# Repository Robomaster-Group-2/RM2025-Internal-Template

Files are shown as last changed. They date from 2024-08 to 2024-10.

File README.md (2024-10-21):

# RM2025-Internal-Template

This is the template project for RM2025 Internal competition.

## Quick start guide

To use this template, clone the template in your terminal with:

```bash
git clone git@github.com:hkustenterprize/RM2025-Internal-Template.git
```

enter the directory with:

```bash
cd RM2025-Internal-Template
```

compile with Makefile

```bash
make -j
```

## Structure

- The directory `./Drivers` and `./Middlewares` contains the HAL drivers generated by CubeMX, you may ignore them.
- The directory `./RM2025-Internal-Core` contains the drivers. You may ignore the FreeRTOS and diagnostic directories as we have already set them up for you.
- You have to implement your own drivers, such as rc or motors driver in `./RM2025-Internal-Core\Drivers`
- You may use the drivers in the Core directory developed by you and implement applications of the tasks in `./Core\Src` and `./Core\Inc`
- Within `./Core/Inc/AppConfig.h`, you could enable/disable certain drivers and configure them. Port configurations had been configured according to the Internal board design.
- Tasks are created in `./Core/Src/UserTask.cpp`. You may set initializing code here
- Most of your code may happen in `./RM2025-Internal-Core/Drivers` and `./Core/Src`.

Wish good luck.

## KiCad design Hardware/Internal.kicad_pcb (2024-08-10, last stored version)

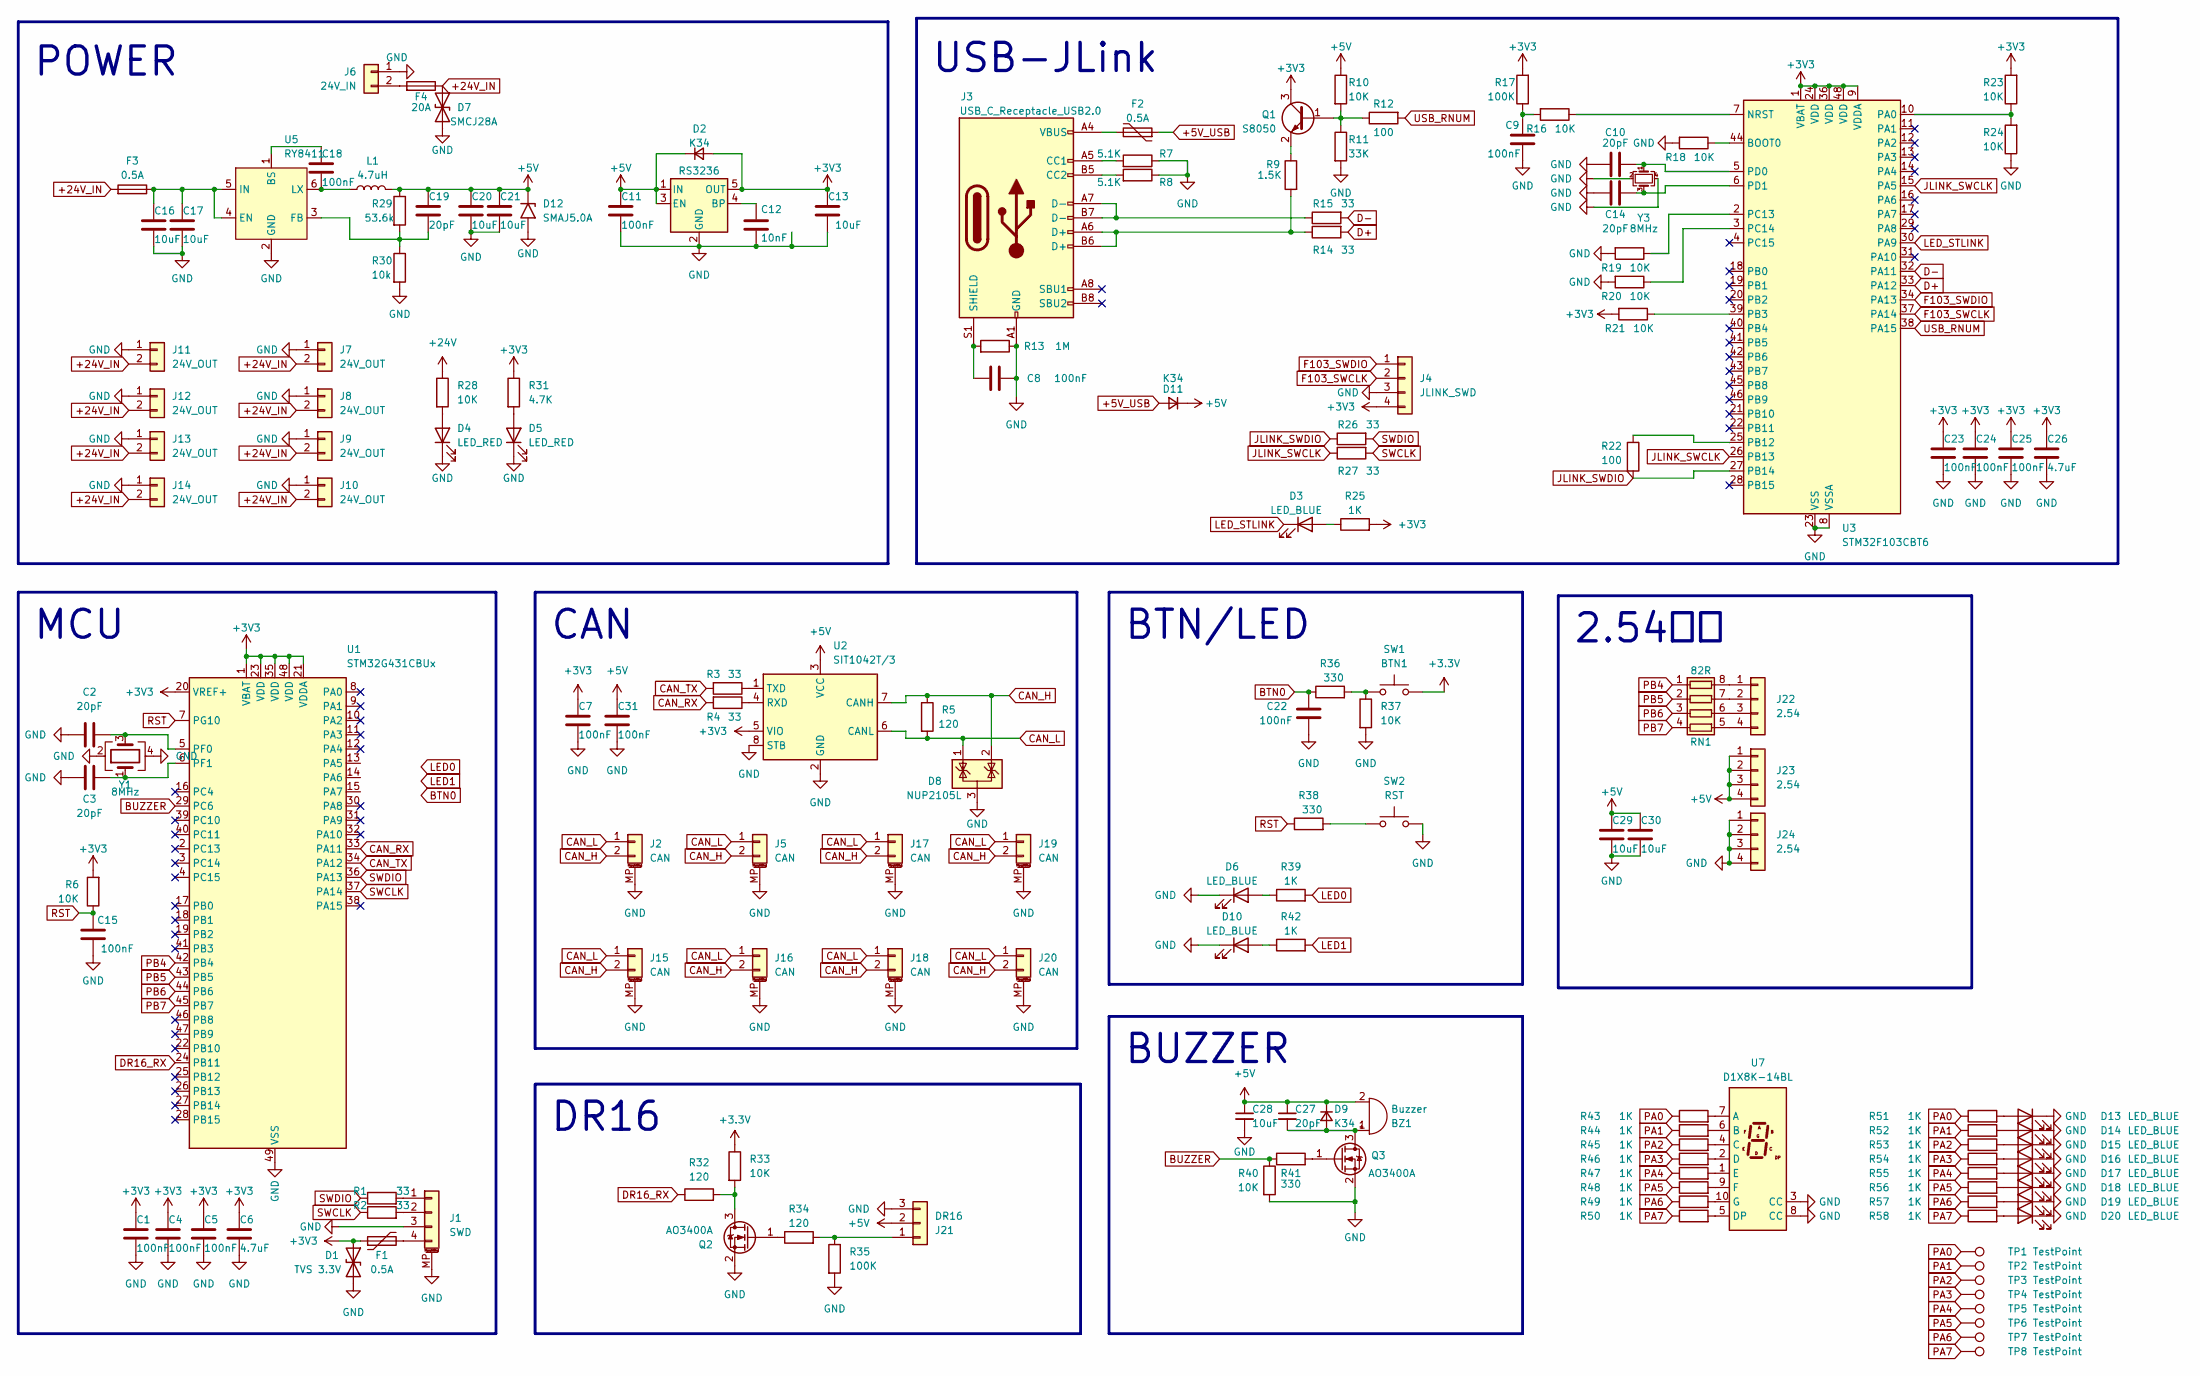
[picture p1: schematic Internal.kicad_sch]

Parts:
BZ1: Buzzer; MLT-9032
C1, C4, C5, C7, C8, C9, C11, C15, C18, C22, C23, C24, C25, C31: 100nF; C_0603_1608Metric
C2, C3, C10, C14, C19, C27: 20pF; C_0603_1608Metric
C6, C26: 4.7uF; C_0603_1608Metric
C12: 10nF; C_0603_1608Metric
C13, C28: 10uF; C_0603_1608Metric
C16, C17, C20, C21, C29, C30: 10uF; C_1206_3216Metric
D1: TVS 3.3V; D_SMF
D2, D9, D11: K34; D_SMF
D3, D6, D10, D13, D14, D15, D16, D17, D18, D19, D20: LED_BLUE; LED_0603_1608Metric
D4, D5: LED_RED; LED_0603_1608Metric
D7: SMCJ28A; D_SMC
D8: NUP2105L; SOT-23
D12: SMAJ5.0A; D_SMA
F1, F2, F3: 0.5A; Fuse_1206_3216Metric
F4: 20A; 1808_Fuse
J1: SWD; Molex_PicoBlade_53398-0471_1x04-1MP_P1.25mm_Vertical
J2, J5, J15, J16, J17, J18, J19, J20: CAN; JST_GH_BM02B-GHS-TBT_1x02-1MP_P1.25mm_Vertical
J3: USB_C_Receptacle_USB2.0; USB_C_Receptacle_HRO_TYPE-C-31-M-12_NO_HOLE
J4: JLINK_SWD; Molex_PicoBlade_53047-0410_1x04_P1.25mm_Vertical
J6: 24V_IN; AMASS_XT30U-M_1x02_P5.0mm_Vertical
J7, J8, J9, J10, J11, J12, J13, J14: 24V_OUT; AMASS_XT30U-F_1x02_P5.0mm_Vertical
J21: DR16; PinHeader_1x03_P2.54mm_Vertical
J22, J23, J24: 2.54; PinSocket_1x04_P2.54mm_Vertical
L1: 4.7uH; L_Cenker_CKCS4020
Q1: S8050; SOT-23
Q2, Q3: AO3400A; SOT-23
R1, R2, R3, R4: 33; R_0402_1005Metric
R5, R32, R34: 120; R_0603_1608Metric
R6: 10K; R_0402_1005Metric
R7, R8: 5.1K; R_0402_1005Metric
R9: 1.5K; R_0603_1608Metric
R10, R16, R18, R19, R20, R21, R23, R24, R28, R33, R37, R40: 10K; R_0603_1608Metric
R11: 33K; R_0603_1608Metric
R12, R22: 100; R_0603_1608Metric
R13: 1M; R_0603_1608Metric
R14, R15, R26, R27: 33; R_0603_1608Metric
R17, R35: 100K; R_0603_1608Metric
R25, R39, R42, R43, R44, R45, R46, R47, R48, R49, R50, R51, R52, R53, R54, R55, R56, R57, R58: 1K; R_0603_1608Metric
R29: 53.6k; R_0603_1608Metric
R30: 10k; R_0603_1608Metric
R31: 4.7K; R_0603_1608Metric
R36, R38, R41: 330; R_0603_1608Metric
RN1: 82R; R_Array_Concave_4x0603
SW1: BTN1; SW_SPST_PTS810
SW2: RST; SW_SPST_PTS810
TP1, TP2, TP3, TP4, TP5, TP6, TP7, TP8: TestPoint; TestPoint_THTPad_2.0x2.0mm_Drill1.0mm
U1: STM32G431CBUx; QFN-48-1EP_7x7mm_P0.5mm_EP5.6x5.6mm
U2: SIT1042T/3; SOIC-8_3.9x4.9mm_P1.27mm
U3: STM32F103CBT6; LQFP-48_7x7mm_P0.5mm
U4: RS3236; SOT-23-5
U5: RY8411; SOT-23-6
U7: D1X8K-14BL; D1X8K
Y1, Y3: 8MHz; Crystal_SMD_3225-4Pin_3.2x2.5mm

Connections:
+3.3V: R33.1, SW1.2
+3V3: C1.2, C4.2, C5.2, C6.2, C7.2, C13.1, C23.2, C24.2, C25.2, C26.2, D1.1 (A1), D2.2 (A), F1.1, J4.4, Q1.3 (C), R6.2, R17.2, R21.2, R23.2, R25.2, R31.1, U1.1 (VBAT), U1.20 (VREF+), U1.21 (VDDA), U1.23 (VDD), U1.35 (VDD), U1.48 (VDD), U2.5 (VIO), U3.1 (VBAT), U3.9 (VDDA), U3.24 (VDD), U3.36 (VDD), U3.48 (VDD), U4.5 (OUT)
+5V: BZ1.2 (+), C11.1, C19.1, C20.1, C21.1, C27.1, C28.1, C29.1, C30.1, C31.2, D2.1 (K), D9.1 (K), D11.1 (K), D12.1 (A1), J21.2, J23.1, J23.2, J23.3, J23.4, L1.2, R10.1, R29.1, U2.3 (VCC), U4.1 (IN), U4.3 (EN)
+5V_USB: D11.2 (A), F2.1
+24V: R28.1
+24V_IN: D7.1 (A1), F3.2, F4.1, J7.2, J8.2, J9.2, J10.2, J11.2, J12.2, J13.2, J14.2
BTN0: C22.1, R36.1
BUZZER: R40.1, R41.1, U1.29 (PC6)
CAN_H: D8.2 (K), J2.2, J5.2, J15.2, J16.2, J17.2, J18.2, J19.2, J20.2, R5.1, U2.7 (CANH)
CAN_L: D8.1 (K), J2.1, J5.1, J15.1, J16.1, J17.1, J18.1, J19.1, J20.1, R5.2, U2.6 (CANL)
CAN_RX: R4.2, U1.33 (PA11)
CAN_TX: R3.2, U1.34 (PA12)
D+: R14.2, U3.33 (PA12)
D-: R15.2, U3.32 (PA11)
DR16_RX: R32.1, U1.24 (PB11)
F103_SWCLK: J4.2, U3.37 (PA14)
F103_SWDIO: J4.1, U3.34 (PA13)
GND: C1.1, C2.1, C3.1, C4.1, C5.1, C6.1, C7.1, C8.1, C9.2, C10.1, C11.2, C12.2, C13.2, C14.1, C15.2, C16.2, C17.2, C20.2, C21.2, C22.2, C23.1, C24.1, C25.1, C26.1, C28.2, C29.2, C30.2, C31.1, D1.2 (A2), D4.1 (K), D5.1 (K), D6.1 (K), D7.2 (A2), D8.3 (A), D10.1 (K), D12.2 (A2), D13.1 (K), D14.1 (K), D15.1 (K), D16.1 (K), D17.1 (K), D18.1 (K), D19.1 (K), D20.1 (K), J1.3, J1.MP (MountPin), J2.MP (MountPin), J3.A1 (GND), J3.A12 (GND), J3.B1 (GND), J3.B12 (GND), J4.3, J5.MP (MountPin), J6.1, J7.1, J8.1, J9.1, J10.1, J11.1, J12.1, J13.1, J14.1, J15.MP (MountPin), J16.MP (MountPin), J17.MP (MountPin), J18.MP (MountPin), J19.MP (MountPin), J20.MP (MountPin), J21.3, J24.1, J24.2, J24.3, J24.4, Q2.2 (S), Q3.2 (S), R7.1, R8.1, R11.2, R13.1, R18.2, R19.2, R20.2, R24.1, R30.2, R35.2, R37.2, R40.2, SW2.2, U1.49 (VSS), U2.2 (GND), U2.8 (STB), U3.8 (VSSA), U3.23 (VSS), U3.35 (VSS), U3.47 (VSS), U4.2 (GND), U5.2 (GND), U7.3 (CC), U7.8 (CC), Y1.2, Y1.4, Y3.2, Y3.4
JLINK_SWCLK: R27.1, U3.15 (PA5), U3.26 (PB13)
JLINK_SWDIO: R22.2, R26.1, U3.27 (PB14)
LED0: R39.2
LED1: R42.2
LED_STLINK: D3.1 (K), U3.30 (PA9)
unnamed: BZ1.1 (-), C27.2, D9.2 (A), Q3.3 (D)
unnamed: C9.1, R16.2, R17.1
unnamed: D3.2 (A), R25.1
unnamed: D4.2 (A), R28.2
unnamed: D5.2 (A), R31.2
unnamed: D6.2 (A), R39.1
unnamed: D10.2 (A), R42.1
unnamed: D13.2 (A), R51.2
unnamed: D14.2 (A), R52.2
unnamed: D15.2 (A), R53.2
unnamed: D16.2 (A), R54.2
unnamed: D17.2 (A), R55.2
unnamed: D18.2 (A), R56.2
unnamed: D19.2 (A), R57.2
unnamed: D20.2 (A), R58.2
unnamed: F2.2, J3.A4 (VBUS), J3.A9 (VBUS), J3.B4 (VBUS), J3.B9 (VBUS)
unnamed: J1.1, R1.2
unnamed: J1.2, R2.2
unnamed: F1.2, J1.4
unnamed: J3.A5 (CC1), R7.2
unnamed: J3.B5 (CC2), R8.2
unnamed: J3.A6 (D+), J3.B6 (D+), R9.2, R14.1
unnamed: J3.A7 (D-), J3.B7 (D-), R15.1
unnamed: C8.2, J3.S1 (SHIELD), R13.2
unnamed: F4.2, J6.2
unnamed: J21.1, R34.2, R35.1
unnamed: J22.1, RN1.8 (R1.2)
unnamed: J22.2, RN1.7 (R2.2)
unnamed: J22.3, RN1.6 (R3.2)
unnamed: J22.4, RN1.5 (R4.2)
unnamed: Q1.1 (B), R10.2, R11.1, R12.1
unnamed: Q1.2 (E), R9.1
unnamed: Q2.3 (D), R32.2, R33.2
unnamed: Q2.1 (G), R34.1
unnamed: Q3.1 (G), R41.2
unnamed: R36.2, R37.1, SW1.1
unnamed: R38.2, SW2.1
unnamed: C2.2, U1.5 (PF0), Y1.3
unnamed: C3.2, U1.6 (PF1), Y1.1
unnamed: R4.1, U2.4 (RXD)
unnamed: R3.1, U2.1 (TXD)
unnamed: R18.1, U3.44 (BOOT0)
unnamed: R16.1, U3.7 (NRST)
unnamed: R23.1, R24.2, U3.10 (PA0)
unnamed: R21.1, U3.39 (PB3)
unnamed: R22.1, U3.25 (PB12)
unnamed: R19.1, U3.2 (PC13)
unnamed: R20.1, U3.3 (PC14)
unnamed: C10.2, U3.5 (PD0), Y3.1
unnamed: C14.2, U3.6 (PD1), Y3.3
unnamed: C12.1, U4.4 (BP)
unnamed: C18.1, U5.1 (BS)
unnamed: C16.1, C17.1, F3.1, U5.4 (EN), U5.5 (IN)
unnamed: C19.2, R29.2, R30.1, U5.3 (FB)
unnamed: C18.2, L1.1, U5.6 (LX)
unnamed: R43.2, U7.7 (A)
unnamed: R44.2, U7.6 (B)
unnamed: R45.2, U7.4 (C)
unnamed: R46.2, U7.2 (D)
unnamed: R50.2, U7.5 (DP)
unnamed: R47.2, U7.1 (E)
unnamed: R48.2, U7.9 (F)
unnamed: R49.2, U7.10 (G)
PA0: R43.1, R51.1, TP1.1
PA1: R44.1, R52.1, TP2.1
PA2: R45.1, R53.1, TP3.1
PA3: R46.1, R54.1, TP4.1
PA4: R47.1, R55.1, TP5.1
PA5: R48.1, R56.1, TP6.1
PA6: R49.1, R57.1, TP7.1
PA7: R50.1, R58.1, TP8.1
PB4: RN1.1 (R1.1), U1.42 (PB4)
PB5: RN1.2 (R2.1), U1.43 (PB5)
PB6: RN1.3 (R3.1), U1.44 (PB6)
PB7: RN1.4 (R4.1), U1.45 (PB7)
RST: C15.1, R6.1, R38.1, U1.7 (PG10)
SWCLK: R2.1, R27.2, U1.37 (PA14)
SWDIO: R1.1, R26.2, U1.36 (PA13)
USB_RNUM: R12.2, U3.38 (PA15)

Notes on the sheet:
2.54排针
BUZZER
USB-JLink
POWER
BTN/LED
DR16
CAN
MCU

Board: 2 copper layers, 161 parts (8 on the bottom side), 99 nets, no tracks yet.

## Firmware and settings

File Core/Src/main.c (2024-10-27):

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
/* Includes ------------------------------------------------------------------*/
#include "main.h"
#include "dma.h"
#include "tim.h"
#include "usart.h"
#include "gpio.h"


void SystemClock_Config(void);
/**
  * @brief  The application entry point.
  * @retval int
  */
int main(void)
{

  /* MCU Configuration--------------------------------------------------------*/

  /* Reset of all peripherals, Initializes the Flash interface and the Systick. */
  HAL_Init();

  /* Configure the system clock */
  SystemClock_Config();

  /* Initialize all configured peripherals */
  MX_GPIO_Init();
  MX_DMA_Init();
  MX_TIM1_Init();
  MX_TIM2_Init();
  MX_USART3_UART_Init();
  MX_USART1_UART_Init();
  /* USER CODE BEGIN 2 */
  // Write the option bytes, !!DO NOT MODIFY!!
  FLASH_OBProgramInitTypeDef pOBInit;
  HAL_FLASHEx_OBGetConfig(&pOBInit);
  if (!((pOBInit.USERConfig & FLASH_OPTR_nSWBOOT0_Msk) == OB_BOOT0_FROM_OB &&
        (pOBInit.USERConfig & FLASH_OPTR_nBOOT0_Msk) == OB_nBOOT0_SET &&
        (pOBInit.USERConfig & FLASH_OPTR_NRST_MODE_Msk) == OB_NRST_MODE_GPIO &&
        (pOBInit.USERConfig & FLASH_OPTR_BOR_LEV_Msk) == OB_BOR_LEVEL_4 &&
        (pOBInit.USERConfig & FLASH_OPTR_nRST_STOP_Msk) == OB_STOP_RST &&
        (pOBInit.USERConfig & FLASH_OPTR_nRST_STDBY_Msk) == OB_STANDBY_RST &&
        (pOBInit.USERConfig & FLASH_OPTR_nRST_SHDW_Msk) == OB_SHUTDOWN_RST
  )) {
      __disable_irq();
      HAL_FLASH_Unlock();
      HAL_FLASH_OB_Unlock();

      pOBInit.OptionType = OPTIONBYTE_USER;
      pOBInit.USERType = 0;
      pOBInit.USERConfig = 0;

      pOBInit.USERType |= OB_USER_nSWBOOT0;
      pOBInit.USERConfig |= OB_BOOT0_FROM_OB;
      pOBInit.USERType |= OB_USER_nBOOT0;
      pOBInit.USERConfig |= OB_nBOOT0_SET;
      pOBInit.USERType |= OB_USER_NRST_MODE;
      pOBInit.USERConfig |= OB_NRST_MODE_GPIO;
      pOBInit.USERType |= OB_USER_BOR_LEV;
      pOBInit.USERConfig |= OB_BOR_LEVEL_4;
      pOBInit.USERType |= OB_USER_nRST_STOP;
      pOBInit.USERConfig |= OB_STOP_RST;
      pOBInit.USERType |= OB_USER_nRST_STDBY;
      pOBInit.USERConfig |= OB_STANDBY_RST;
      pOBInit.USERType |= OB_USER_nRST_SHDW;
      pOBInit.USERConfig |= OB_SHUTDOWN_RST;
      pOBInit.USERType |= OB_USER_IRHEN;
      pOBInit.USERConfig |= OB_IRH_ENABLE;
      HAL_FLASHEx_OBProgram(&pOBInit);
      HAL_FLASH_OB_Launch();
      HAL_FLASH_OB_Lock();
      HAL_FLASH_Lock();
      __enable_irq();
  }

  extern void startRTOS();
  startRTOS();
  /* USER CODE END 2 */

  /* Infinite loop */
  /* USER CODE BEGIN WHILE */
  while (1)
  {
    /* USER CODE END WHILE */

    /* USER CODE BEGIN 3 */
  }
  /* USER CODE END 3 */
}

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


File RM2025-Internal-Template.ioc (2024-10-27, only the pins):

Mcu.UserName=STM32G431CBUx
PA0.GPIO_Label=BUZZER
PA0.Signal=S_TIM2_CH1
PA10.Signal=USART1_RX
PA13.Signal=SYS_JTMS-SWDIO
PA14.Signal=SYS_JTCK-SWCLK
PA8.GPIO_Label=WS2812
PA8.Signal=S_TIM1_CH1
PB10.Signal=USART3_TX
PB11.Signal=USART3_RX
PC4.Signal=USART1_TX
PF0-OSC_IN.Signal=RCC_OSC_IN
PF1-OSC_OUT.Signal=RCC_OSC_OUT

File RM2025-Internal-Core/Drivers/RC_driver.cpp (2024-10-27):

#include "gpio.h"
#include "main.h"
#include "usart.h"
#include "RC_driver.hpp"

#define rxBuffer_size 25
#define txBuffer_size 25

static uint8_t rxBuffer[rxBuffer_size] ;
static uint16_t txBuffer[txBuffer_size] ;

struct DecodedData{
  uint16_t Header ;
  uint16_t Ch_1 ;
  uint16_t Ch_2 ;
  uint16_t Ch_3 ;
  uint16_t Ch_4 ;
  uint16_t Ch_5 ;
  uint16_t Ch_6 ;
  uint16_t Ch_7 ;
  uint16_t Ch_8 ;
  uint16_t Ch_9 ;
  uint16_t Ch_10 ;
  uint16_t Ch_11 ;
  uint16_t Ch_12 ;
  uint16_t Ch_13 ;
  uint16_t Ch_14 ;
  uint16_t Ch_15 ;
  uint16_t Ch_16 ;
  uint16_t Ch_17 ;
  uint16_t Ch_18 ;
  uint16_t frame_lost ;
  uint16_t failsafe_activated ;
  uint16_t Footer ;
} decodedData ;


void rxCallback(UART_HandleTypeDef *huart, uint16_t size){
  decodedData.Header = rxBuffer[0] ;
  decodedData.Ch_1 = ((rxBuffer[2] & 0b111) << 8) | (rxBuffer[1]) ;
  decodedData.Ch_2 = ((rxBuffer[3] & 0b111111) << 5) | ((rxBuffer[2] & 0b11111) >> 3) ;
  decodedData.Ch_3 = ((rxBuffer[5] & 0b1) << 10) | (rxBuffer[4] << 2) | ((rxBuffer[3] & 0b11) >> 6)  ;
  decodedData.Ch_4 = ((rxBuffer[6] & 0b1111) << 7) | ((rxBuffer[5] & 0b1111111) >> 1) ;
  decodedData.Ch_5 = ((rxBuffer[7] & 0b1111111) << 4) | ((rxBuffer[6] & 0b1111) >> 4) ;
  decodedData.Ch_6 = ((rxBuffer[9] & 0b11) << 9) | (rxBuffer[8] << 1) | ((rxBuffer[7] & 0b1) >> 7) ;
  decodedData.Ch_7 = ((rxBuffer[10] & 0b11111) << 6) | ((rxBuffer[9] & 0b111111) >> 2) ; 
  decodedData.Ch_8 = (rxBuffer[11] << 3) | ((rxBuffer[10] & 0b111) >> 5) ; 
  decodedData.Ch_9 = ((rxBuffer[13] & 0b111) << 8) | (rxBuffer[12]) ;
  decodedData.Ch_10 = ((rxBuffer[14] & 0b111111) << 5) | ((rxBuffer[13] & 0b11111) >> 3) ; 
  decodedData.Ch_11 = ((rxBuffer[16] & 0b1) << 10) | (rxBuffer[15] << 2) | ((rxBuffer[14] & 0b11) >> 6) ;
  decodedData.Ch_12 = ((rxBuffer[17] & 0b1111) << 7) | ((rxBuffer[16] & 0b1111111) >> 1) ;
  decodedData.Ch_13 = ((rxBuffer[18] &0b1111111) << 4) | ((rxBuffer[17] & 0b1111) >> 4) ;
  decodedData.Ch_14 = ((rxBuffer[20] &0b11) << 9) | (rxBuffer[19] << 1) | ((rxBuffer[18] &0b1) >> 7) ;
  decodedData.Ch_15 = ((rxBuffer[21] &0b11111) << 6) | ((rxBuffer[20] &0b111111) >> 2) ;
  decodedData.Ch_16 = (rxBuffer[22] << 3) | ((rxBuffer[21] &0b111) >> 5) ;
  decodedData.Ch_17 = (rxBuffer[23] &0b1) ;
  decodedData.Ch_18 = (rxBuffer[23] &0b1) ;
  decodedData.frame_lost = (rxBuffer[23] &0b1) ;
  decodedData.failsafe_activated = (rxBuffer[23] &0b1) ;
  decodedData.Footer = rxBuffer[24] ;
  HAL_UARTEx_ReceiveToIdle_IT(&huart3, rxBuffer, sizeof(rxBuffer)) ;
}


void RC_driver_Task(void *pvPara){
    HAL_UART_RegisterRxEventCallback(&huart3, rxCallback) ;
    HAL_UARTEx_ReceiveToIdle_IT(&huart3, rxBuffer, sizeof(rxBuffer)) ;
    
    while (1) {
        HAL_Delay(1);
    }
}

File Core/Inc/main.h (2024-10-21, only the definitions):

#define BUZZER_Pin GPIO_PIN_0
#define BUZZER_GPIO_Port GPIOA
#define WS2812_Pin GPIO_PIN_8
#define WS2812_GPIO_Port GPIOA

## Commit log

2024-08-09 Add Hardware Design
    [Internal.kicad_pcb, Internal.kicad_sch]
2024-08-10 fix pcb bug
    [Internal.kicad_pcb, Internal.kicad_sch]
2024-08-10 update PCB
    [Internal.kicad_pcb, Internal.kicad_sch]
2024-09-02 WS2812 Driver
2024-09-02 update WS2812 Driver
2024-10-27 Remote driver in UserTask.cpp
2024-10-27 rc driver

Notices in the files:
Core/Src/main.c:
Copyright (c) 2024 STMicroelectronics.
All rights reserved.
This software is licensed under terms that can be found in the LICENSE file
